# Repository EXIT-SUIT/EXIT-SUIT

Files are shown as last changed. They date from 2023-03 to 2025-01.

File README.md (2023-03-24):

GithubBanner2

# EXIT SUIT
 
The EXIT SUIT is a full-body force-feedback navigation and performance suit for Virtual Reality. This repo contains our code so far for connecting the EXIT SUIT to Unity. 

We are building a community of supporters to help us bring the EXIT SUIT to the public. We recognise it is an important step in the development of human/computer interface and virtual reality.   
<br/><br/> 
ExitImage2   
<br/>
# Community  
 
* Youtube: https://www.youtube.com/@WillieWinkler

* Instagram: https://www.instagram.com/exitsuit/

* Patreon: https://www.patreon.com/EXITSUIT

* Discord: https://discord.gg/Rf7WjFDc

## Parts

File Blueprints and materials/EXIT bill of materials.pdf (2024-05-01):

## Bill of Materials for the EXIT SUIT Revised 31 Jan 2024

CNC cut ply parts- 18mm birch ply
-Use 6mm wide down spiral cutter for cnc machine
I finish my plywood parts with a Wax-oil with added whitener

Spigot
Solid Nylon Bar - 50mm round bar x 260mm long (to be turned on engineering lathe to fit into base bearing 40mm at bottom and up inside tube for 150mm at top)

‘Kingpin’ Metal support column
x1 45mm id Bearing pillow block for base (https://www.ebay.co.uk/itm/UCF-Metric-Self-Lube-Square-Flange-Pillow-Block-Bearing-UCF201-UCF218/222936495315) (bottom bearing) x1 Sealed bearing id 50mm od 90mm width 20mm (https://www.ebay.co.uk/itm/264521502782) (top bearing)
Laser cut 3mm stainless steel components
x1 OD 50mm seamless steel tube 3mm wall (or 5mm wall) (Cold Drawn Seamless in UK or ‘Drawn over Mandrel’ in USA) steel tube (800mm long - shorten to fit crotch height)

It iOS also possible to use a length of easy to find 48.3mm scaffolding tube. The issue here is that it is not so easy to find a sealed bearing (top bearing in base under floorboard) that fits a scaffold tube, so you’d need to turn an additional nylon bush to fit a larger bearing or add vertical welds to the surface of the tube before grinding them back to fit.
Add additional 70mm Nylon round bar x 40mm long (if using this scaffolding tube with bush option and increase top bearing to 60mm id)
Remember the technical drawing for the plywood cutting will need to be adjusted to fit this new bearing size.

Skin
You will need to add a harness or ‘skin’ part to hold yourself into the spine. The simplest way to do this is with a ‘two point safety harness’, customised by having it’s metal hanging point D rings cut off and with holes punched into the belts to enable it to be bolted into the pelvis. https://www.ebay.co.uk/itm/335024775861

Alternatively, you might consider making a leather or canvas version. There are several examples sown in the various EXIT SUIT videos. Fitted custom made skins can be more comfortable and quicker to put on and take off. They might also offer more surface area coverage which is useful if adding haptics and tracking.

Box of 5.0 50mm screws (Torx head)
Box of 5.0 30mm screws (Torx head)
30m 4mm bungee cord (https://www.ebay.co.uk/itm/180822655761)
10m 6mm bungee cord
1m of seatbelts webbing
x30 M6 16mm threaded inserts with flange top (https://www.ebay.co.uk/itm/323306435994) x8 M6 alan drive stainless countersunk bolts (https://www.ebay.co.uk/itm/221298706799?var=520181721468) 60mm X2 M10 stainless 55mm coach bolts (https://www.ebay.co.uk/itm/222339677084?var=521196374967)
X2 M10 stainless 75mm coach bolts
x12 M10 Stainless Nyloc Nuts
x14 M10 washers
x4 M10 60mm countersunk bolts (https://www.ebay.co.uk/itm/360915450505)
X8 30mm OD 10mm ID bearings (https://www.ebay.co.uk/itm/223790691007)
x2 M10 16mm button head bolts (https://www.ebay.co.uk/itm/354197940520)
x4 M8 countersunk 40mm bolts, nuts and washers
x8 38mm rubber feet (https://www.ebay.co.uk/itm/325720224691)
Some 1mm leather (softening ‘disks’ layer for vertebrae feet)

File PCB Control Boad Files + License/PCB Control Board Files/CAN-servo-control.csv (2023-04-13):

Qty | Value | Device | Package | Parts | Description
1 |  | CONN_02 | 1X02 | J4 | Multi connection point. Often used as Generic Header-pin footprint for 0.1 inch spaced/style header connections
1 |  | CONN_06SILK_FEMALE_PTH | 1X06 | J1 | Multi connection point. Often used as Generic Header-pin footprint for 0.1 inch spaced/style header connections
10 |  | SPARKFUN-LED_LED0603 | SPARKFUN-LED_LED-0603 | D1, D2, D3, D4, D5, D6, D7, D8, D9, D10 | LED (Generic)
1 | 0.1uF | SPARKFUN_CAP0603-CAP | SPARKFUN_0603-CAP | C1 | Capacitor
1 | 100uF | CPOL-EUE2.5-5 | E2,5-5 | C3 | POLARIZED CAPACITOR, European symbol
10 | 150 | SPARKFUN-RESISTORS_150OHM-0603-1/10W-1% | SPARKFUN-RESISTORS_0603 | R1, R2, R3, R4, R5, R6, R7, R8, R9, R10 | 150Ω resistor
6 | 455-1750-1-ND | CONN_03 | 1X03 | J3, J5, J6, J7, J8, J9 | Multi connection point. Often used as Generic Header-pin footprint for 0.1 inch spaced/style header connections
1 | 470uF | CPOL-EUE2.5-6 | E2,5-6 | C2 | POLARIZED CAPACITOR, European symbol
1 | RESET | 431256038716 | 431256038716 | S1 | WS-TST, 6*6mm right angle Tact switch,THT, height 3.85mm, 4 pins, black actuator, 160gf
1 | TEENSY_3.6_DIL | TEENSY_3.6_DIL | TEENSY_3.6_DIL | U$1 | Teensy 3.6 DIL Package
1 | XT30PW-M | XT30PW-M | XT30PWM | J2 | 30A Low Temperature Rise Fire Retardant Plug

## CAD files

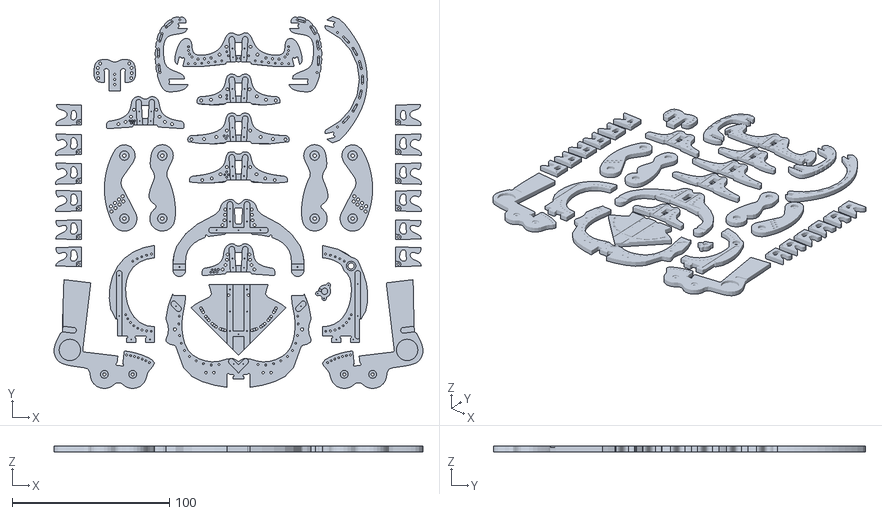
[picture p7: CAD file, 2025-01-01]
Blueprints and materials/1-5-flat EXIT-01.01.2025.stl
234.3 x 236.2 x 3.60

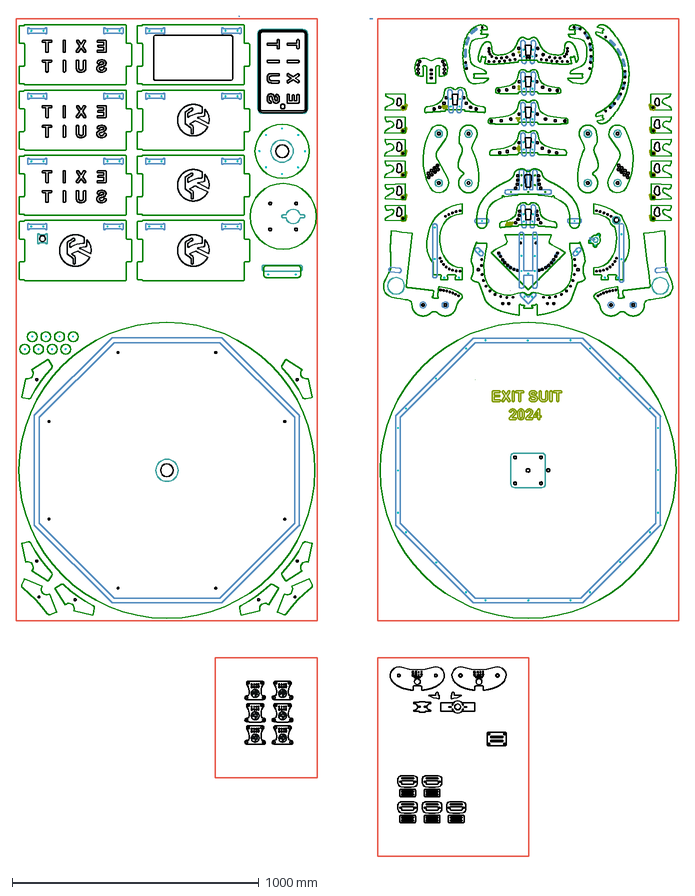
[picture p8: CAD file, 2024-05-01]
Blueprints and materials/EXIT SUIT 2024.dxf
2684.2 x 3405.8 mm

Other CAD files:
Blueprints and materials/assembled-exitsuit.dwg

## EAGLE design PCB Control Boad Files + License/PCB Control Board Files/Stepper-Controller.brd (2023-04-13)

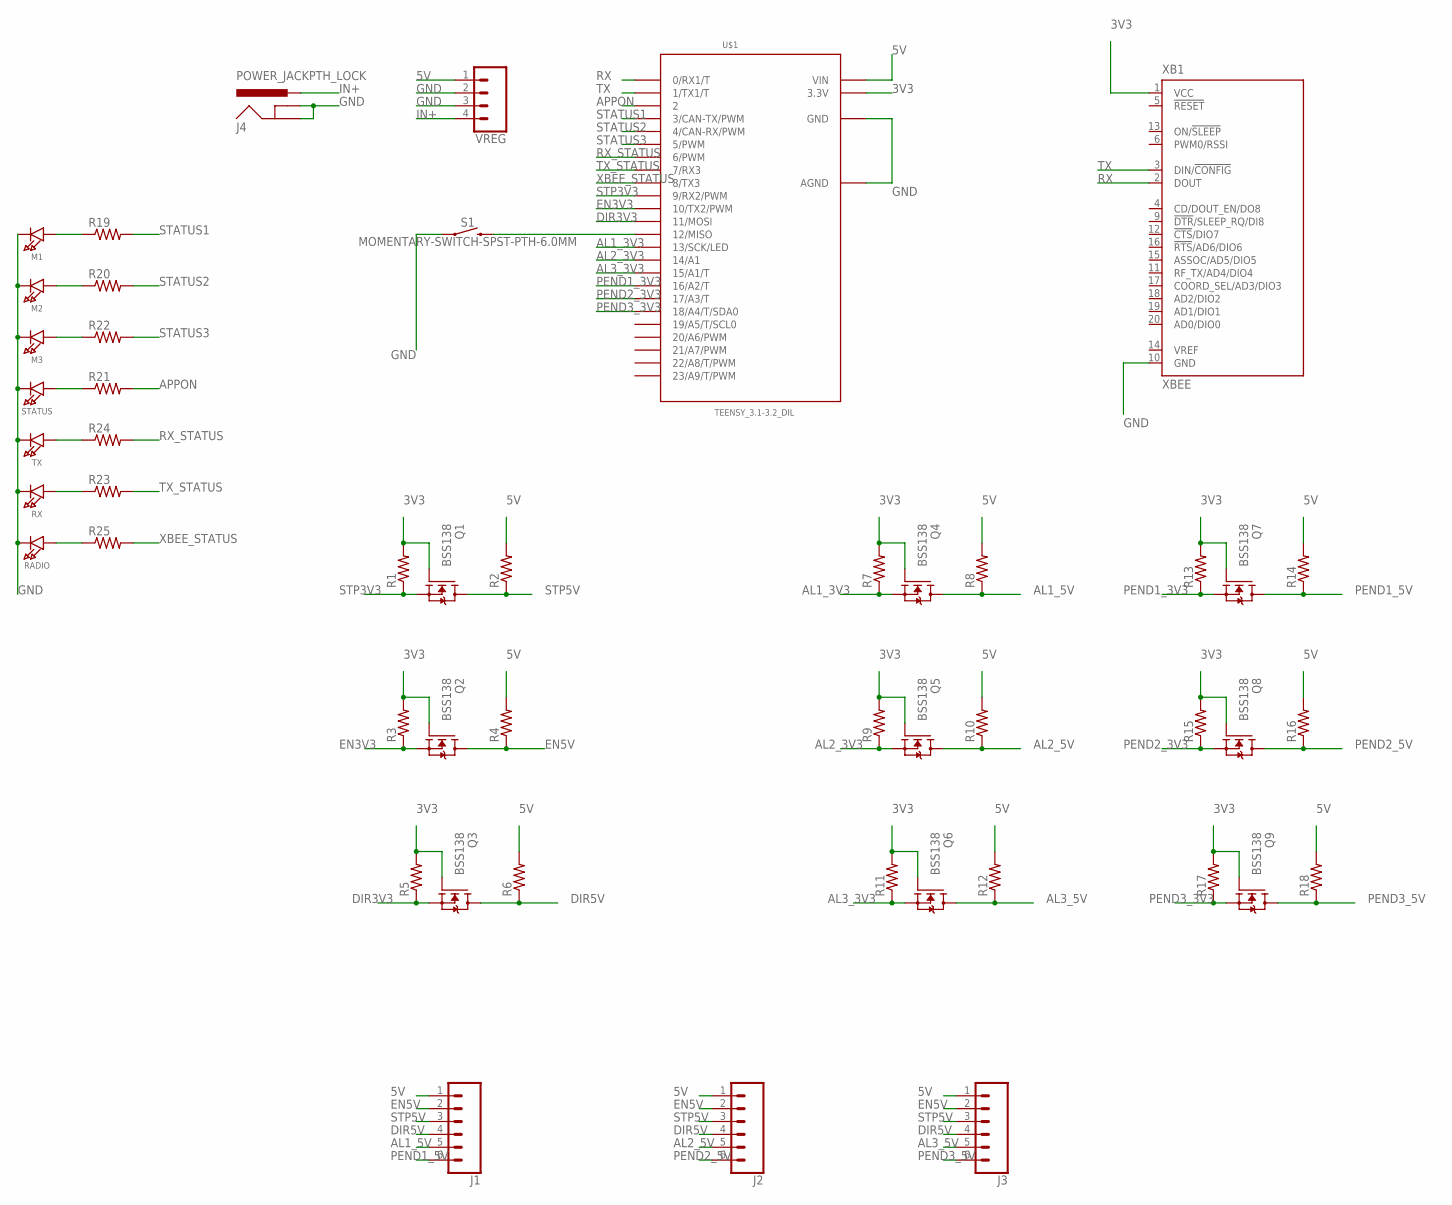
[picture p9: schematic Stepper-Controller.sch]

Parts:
J1, J2, J3: CONN_06NO_SILK_FEMALE_PTH; 1X06_NO_SILK
J4: POWER_JACKPTH_LOCK; POWER_JACK_PTH_LOCK
M1, M2, M3: MICROBUILDER_LED0603; MICROBUILDER_CHIPLED_0603
Q1, Q2, Q3, Q4, Q5, Q6, Q7, Q8, Q9: BSS138; SOT23
R1, R2, R3, R4, R5, R6, R7, R8, R9, R10, R11, R12, R13, R14, R15, R16, R17, R18, R19, R20, R21, R22, R23, R24, R25: CONTROLBOARD_V1.0_SPARKFUN_RESISTOR0603-RES; CONTROLBOARD_V1.0_SPARKFUN_0603-RES
RADIO: MICROBUILDER_LED0603; MICROBUILDER_CHIPLED_0603
RX: MICROBUILDER_LED0603; MICROBUILDER_CHIPLED_0603
S1: MOMENTARY-SWITCH-SPST-PTH-6.0MM; TACTILE_SWITCH_PTH_6.0MM
STATUS: MICROBUILDER_LED0603; MICROBUILDER_CHIPLED_0603
TX: MICROBUILDER_LED0603; MICROBUILDER_CHIPLED_0603
U$1: TEENSY_3.1-3.2_DIL; TEENSY_3.0-3.2&LC_DIL
VREG: CONN_04LONGPADS; 1X04_LONGPADS
XB1: XBEE

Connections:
3V3: Q1.1 (G), Q2.1 (G), Q3.1 (G), Q4.1 (G), Q5.1 (G), Q6.1 (G), Q7.1 (G), Q8.1 (G), Q9.1 (G), R1.2, R3.2, R5.2, R7.2, R9.2, R11.2, R13.2, R15.2, R17.2, U$1.3.3V, XB1.1 (VCC)
5V: J1.1, J2.1, J3.1, R2.2, R4.2, R6.2, R8.2, R10.2, R12.2, R14.2, R16.2, R18.2, U$1.VIN, VREG.1
AL1_3V3: Q4.2 (S), R7.1, U$1.13 (13/SCK/LED)
AL1_5V: J1.5, Q4.3 (D), R8.1
AL2_3V3: Q5.2 (S), R9.1, U$1.14/A0 (14/A1)
AL2_5V: J2.5, Q5.3 (D), R10.1
AL3_3V3: Q6.2 (S), R11.1, U$1.15/A1 (15/A1/T)
AL3_5V: J3.5, Q6.3 (D), R12.1
APPON: R21.2, U$1.2
DIR3V3: Q3.2 (S), R5.1, U$1.11 (11/MOSI)
DIR5V: J1.4, J2.4, J3.4, Q3.3 (D), R6.1
EN3V3: Q2.2 (S), R3.1, U$1.10 (10/TX2/PWM)
EN5V: J1.2, J2.2, J3.2, Q2.3 (D), R4.1
GND: J4.GND, J4.GNDBREAK, M1.C, M2.C, M3.C, RADIO.C, RX.C, S1.1, STATUS.C, TX.C, U$1.AGND, U$1.GND, VREG.2, VREG.3, XB1.10 (GND)
IN+: J4.PWR, VREG.4
unnamed: M1.A, R19.1
unnamed: M2.A, R20.1
unnamed: S1.3 (2), U$1.12 (12/MISO)
unnamed: R21.1, STATUS.A
unnamed: M3.A, R22.1
unnamed: R23.1, RX.A
unnamed: R24.1, TX.A
unnamed: R25.1, RADIO.A
PEND1_3V3: Q7.2 (S), R13.1, U$1.16/A2 (16/A2/T)
PEND1_5V: J1.6, Q7.3 (D), R14.1
PEND2_3V3: Q8.2 (S), R15.1, U$1.17/A3 (17/A3/T)
PEND2_5V: J2.6, Q8.3 (D), R16.1
PEND3_3V3: Q9.2 (S), R17.1, U$1.18/A4 (18/A4/T/SDA0)
PEND3_5V: J3.6, Q9.3 (D), R18.1
RX: U$1.0 (0/RX1/T), XB1.2 (DOUT)
RX_STATUS: R24.2, U$1.6 (6/PWM)
STATUS1: R19.2, U$1.3 (3/CAN-TX/PWM)
STATUS2: R20.2, U$1.4 (4/CAN-RX/PWM)
STATUS3: R22.2, U$1.5 (5/PWM)
STP3V3: Q1.2 (S), R1.1, U$1.9 (9/RX2/PWM)
STP5V: J1.3, J2.3, J3.3, Q1.3 (D), R2.1
TX: U$1.1 (1/TX1/T), XB1.3 (DIN/!CONFIG)
TX_STATUS: R23.2, U$1.7 (7/RX3)
XBEE_STATUS: R25.2, U$1.8 (8/TX3)

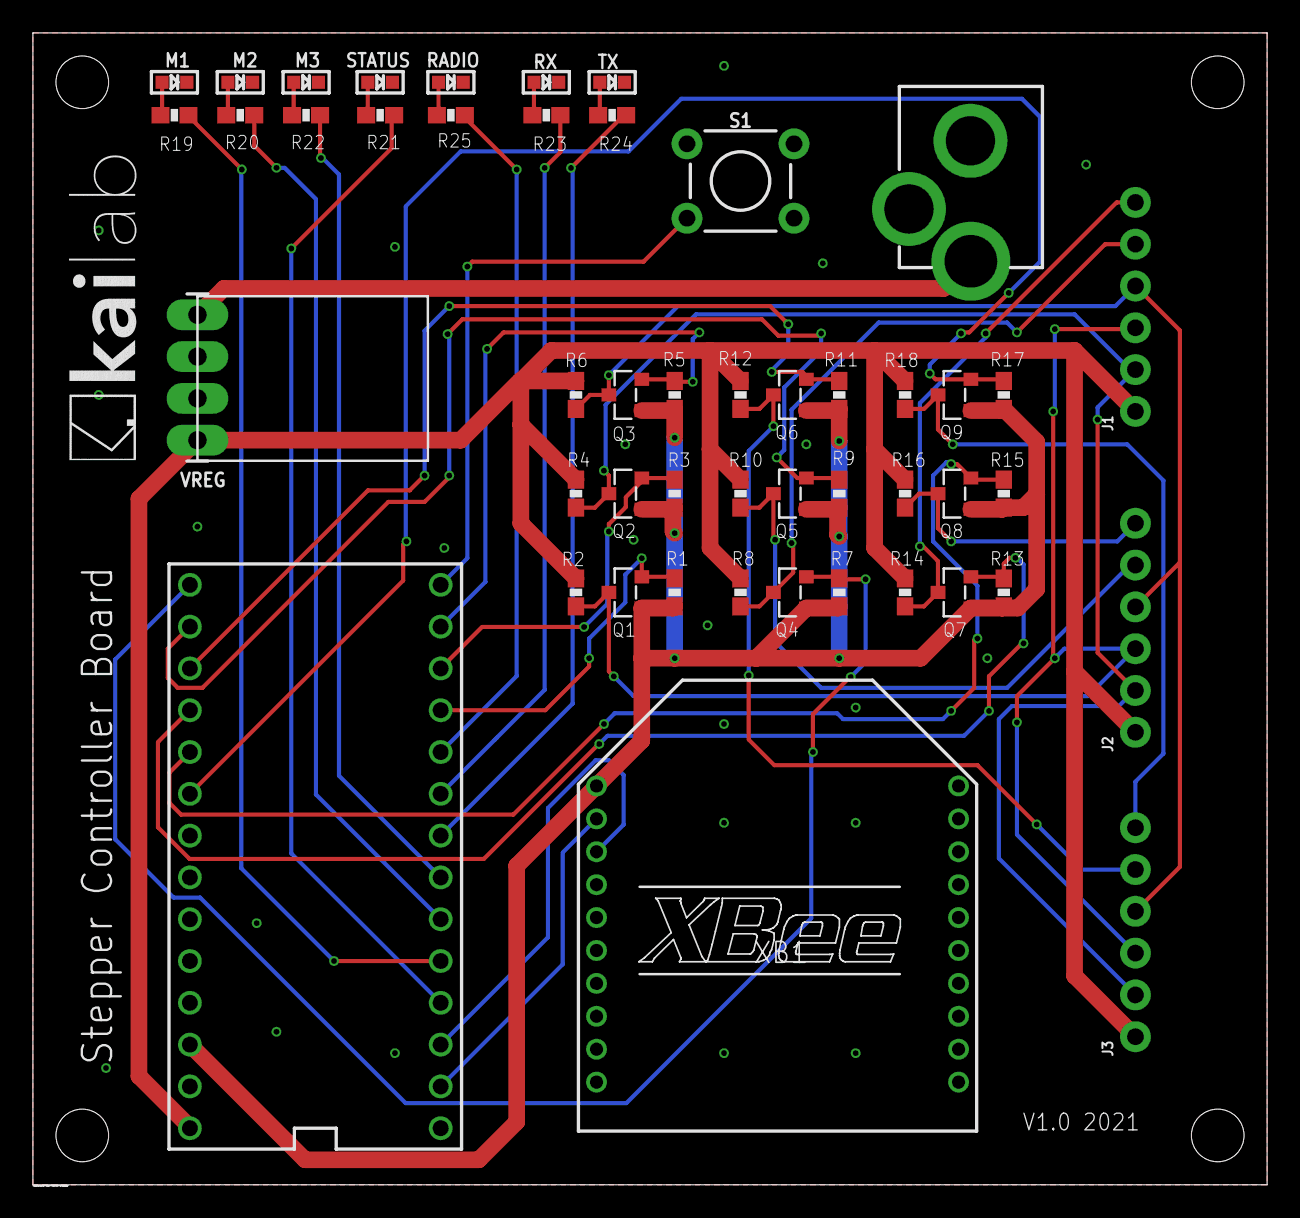
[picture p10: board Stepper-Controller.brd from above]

Board: 2 copper layers, 75.0 x 70.0 mm, 49 parts (0 on the bottom side), 39 nets.

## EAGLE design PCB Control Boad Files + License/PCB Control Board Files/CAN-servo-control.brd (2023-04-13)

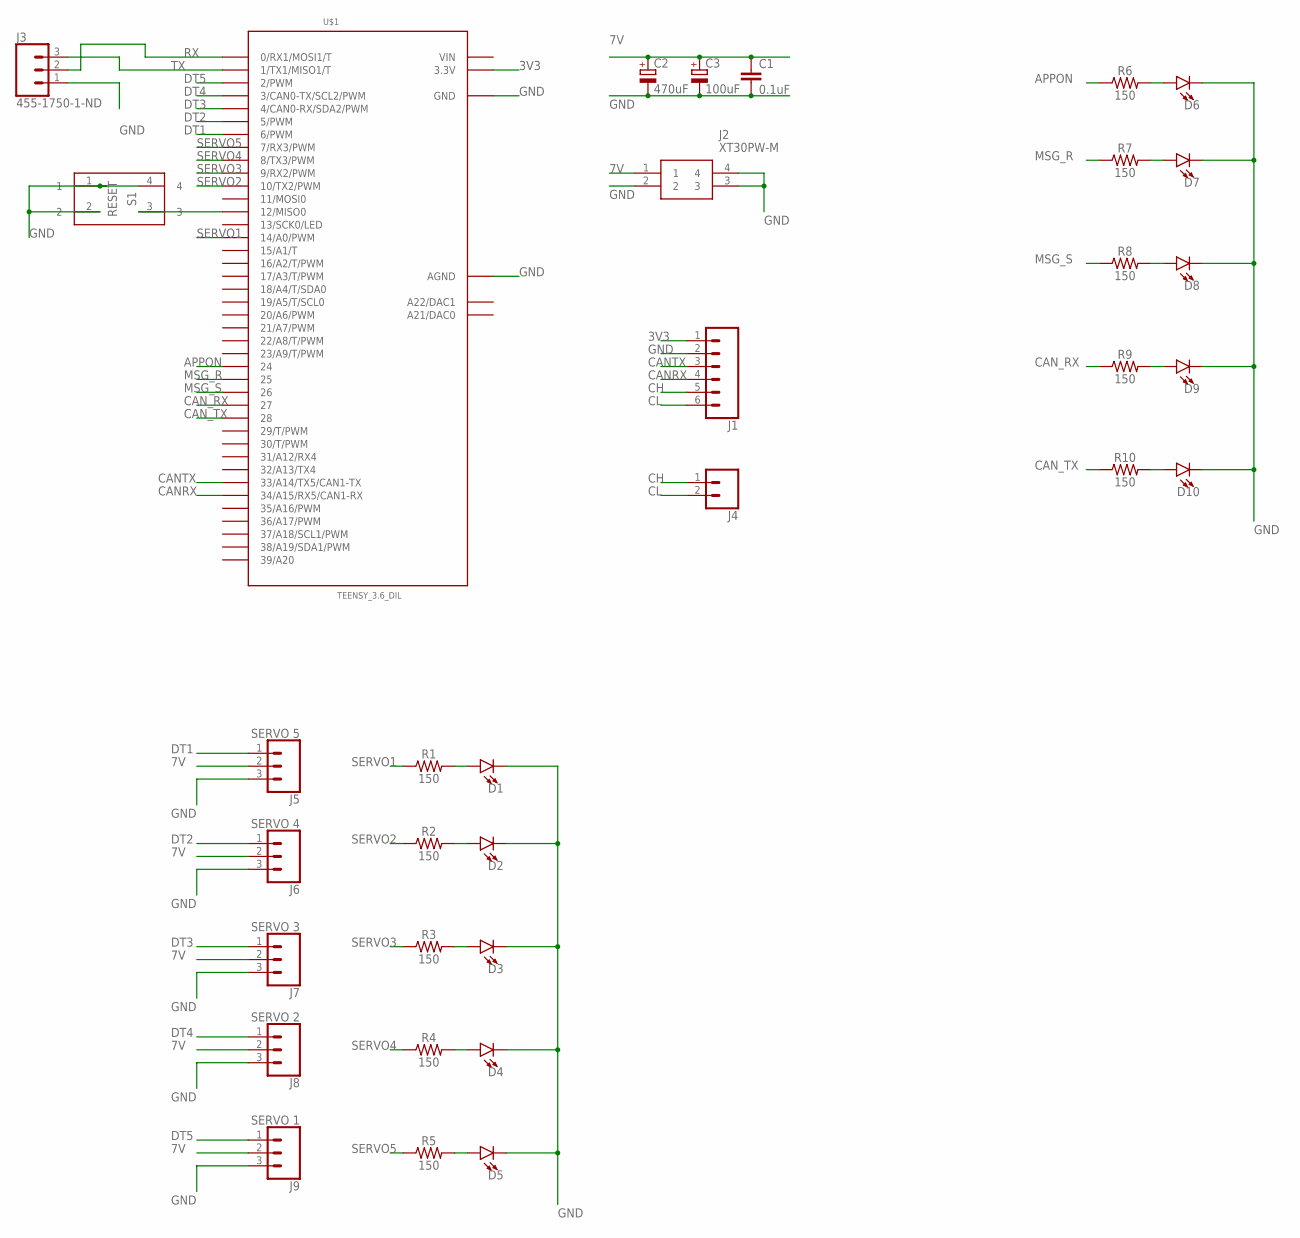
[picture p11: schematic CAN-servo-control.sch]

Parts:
C1: 0.1uF; SPARKFUN_0603-CAP
C2: 470uF; E2,5-6
C3: 100uF; E2,5-5
D1, D2, D3, D4, D5, D6, D7, D8, D9, D10: SPARKFUN-LED_LED0603; SPARKFUN-LED_LED-0603
J1: CONN_06SILK_FEMALE_PTH; 1X06
J2: XT30PW-M; XT30PWM
J3: 455-1750-1-ND; 1X03
J4: CONN_02; 1X02
J5: SERVO 5; 1X03
J6: SERVO 4; 1X03
J7: SERVO 3; 1X03
J8: SERVO 2; 1X03
J9: SERVO 1; 1X03
R1, R2, R3, R4, R5, R6, R7, R8, R9, R10: 150; SPARKFUN-RESISTORS_0603
S1: RESET; 431256038716
U$1: TEENSY_3.6_DIL

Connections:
3V3: J1.1, U$1.3.3V, U$1.3.3V3 (3.3V)
7V: C1.1, C2.+, C3.+, J2.1, J5.2, J6.2, J7.2, J8.2, J9.2
APPON: R6.1, U$1.24
CANRX: J1.4, U$1.34/A15 (34/A15/RX5/CAN1-RX)
CANTX: J1.3, U$1.33/A14 (33/A14/TX5/CAN1-TX)
CAN_RX: R9.1, U$1.27
CAN_TX: R10.1, U$1.28
CH: J1.5, J4.1
CL: J1.6, J4.2
DT1: J5.1, U$1.6 (6/PWM)
DT2: J6.1, U$1.5 (5/PWM)
DT3: J7.1, U$1.4 (4/CAN0-RX/SDA2/PWM)
DT4: J8.1, U$1.3 (3/CAN0-TX/SCL2/PWM)
DT5: J9.1, U$1.2 (2/PWM)
GND: C1.2, C2.-, C3.-, D1.C, D2.C, D3.C, D4.C, D5.C, D6.C, D7.C, D8.C, D9.C, D10.C, J1.2, J2.2, J2.3, J2.4, J3.1, J5.3, J6.3, J7.3, J8.3, J9.3, S1.1, S1.2, S1.4, U$1.AGND, U$1.GND, U$1.GND1 (GND)
MSG_R: R7.1, U$1.25
MSG_S: R8.1, U$1.26
unnamed: S1.3, U$1.12 (12/MISO0)
unnamed: D1.A, R1.2
unnamed: D2.A, R2.2
unnamed: D3.A, R3.2
unnamed: D4.A, R4.2
unnamed: D5.A, R5.2
unnamed: D6.A, R6.2
unnamed: D7.A, R7.2
unnamed: D8.A, R8.2
unnamed: D9.A, R9.2
unnamed: D10.A, R10.2
RX: J3.2, U$1.0 (0/RX1/MOSI1/T)
SERVO1: R1.1, U$1.14/A0 (14/A0/PWM)
SERVO2: R2.1, U$1.10 (10/TX2/PWM)
SERVO3: R3.1, U$1.9 (9/RX2/PWM)
SERVO4: R4.1, U$1.8 (8/TX3/PWM)
SERVO5: R5.1, U$1.7 (7/RX3/PWM)
TX: J3.3, U$1.1 (1/TX1/MISO1/T)
VIN: U$1.VIN

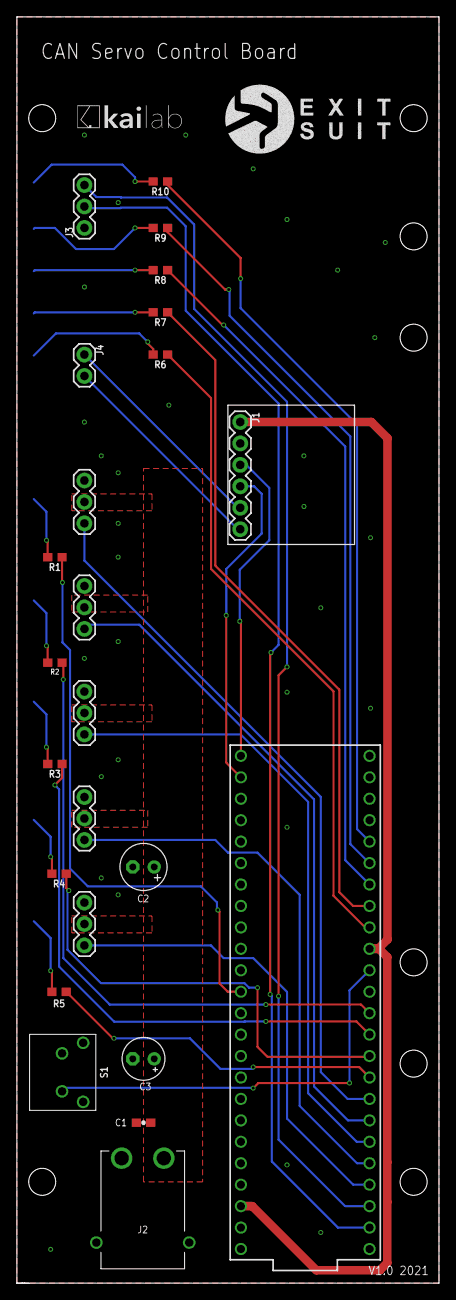
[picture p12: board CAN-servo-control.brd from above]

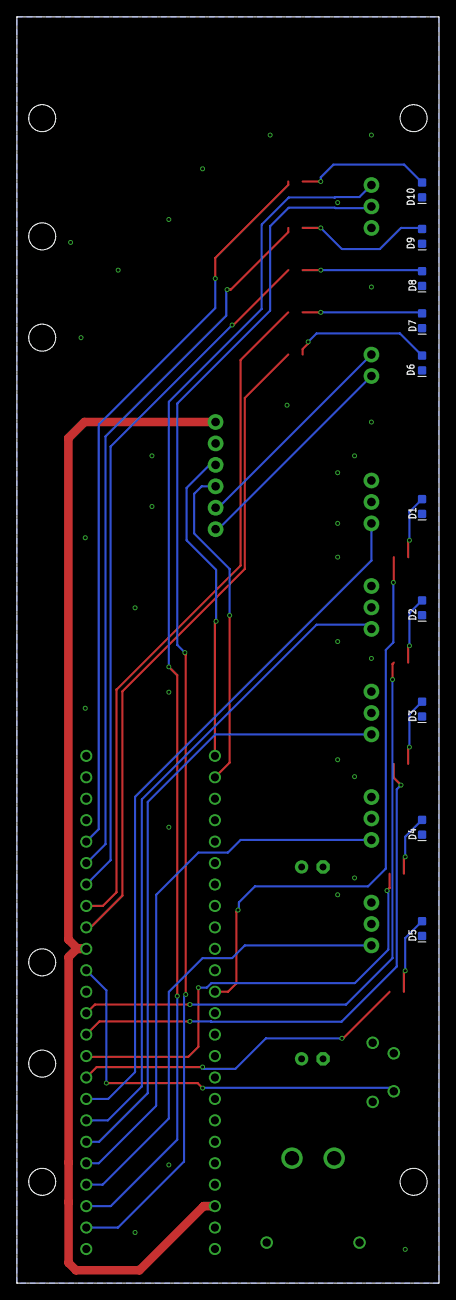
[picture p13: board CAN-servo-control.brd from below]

Board: 2 copper layers, 50.0 x 150.0 mm, 34 parts (10 on the bottom side), 35 nets.

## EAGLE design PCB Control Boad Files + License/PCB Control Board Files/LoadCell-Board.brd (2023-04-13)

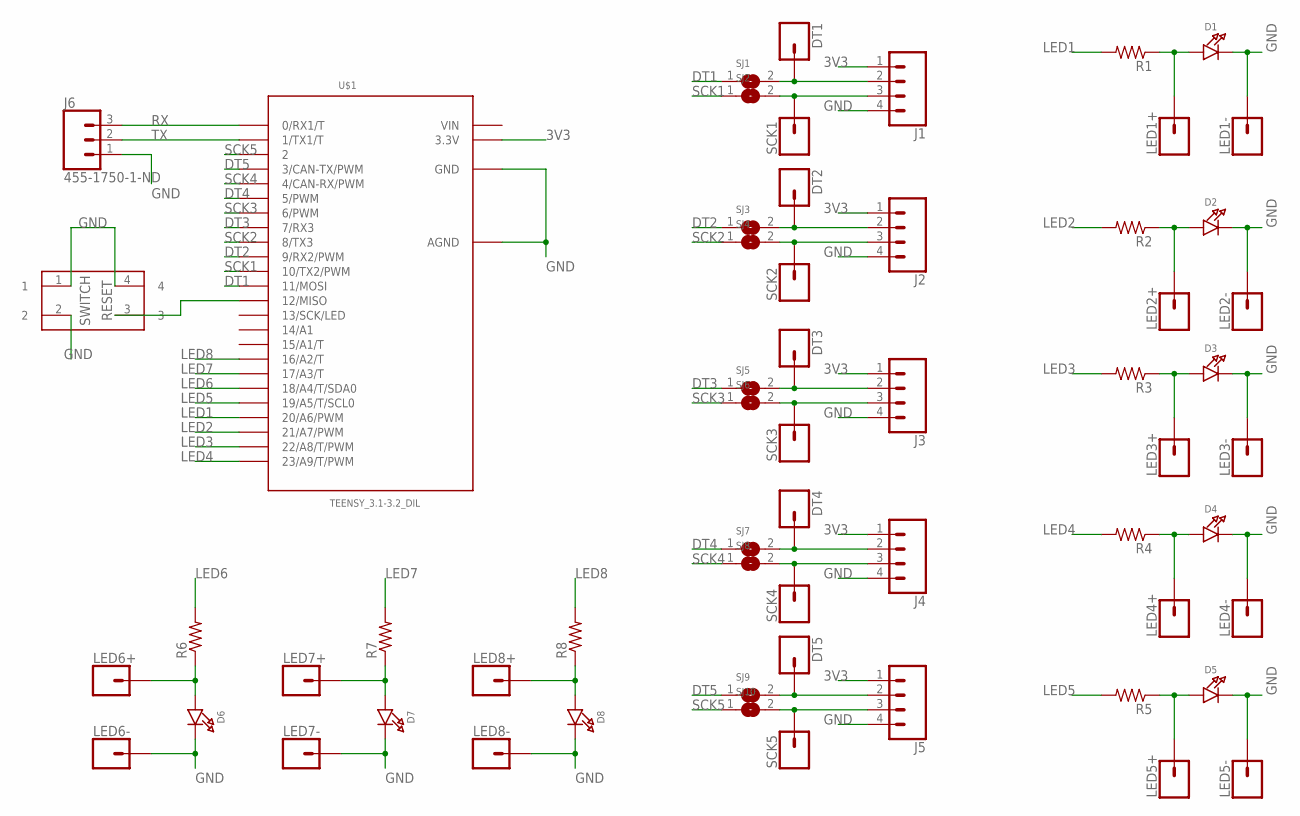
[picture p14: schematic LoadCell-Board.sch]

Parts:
D1, D2, D3, D4, D5, D6, D7, D8: MICROBUILDER_LED0603; MICROBUILDER_CHIPLED_0603
DT1, DT2, DT3, DT4, DT5: CONN_01; 1X01
J1, J2, J3, J4, J5: CONN_041X04_NO_SILK; 1X04_NO_SILK
J6: 455-1750-1-ND; 1X03
LED1+, LED1-, LED2+, LED2-, LED3+, LED3-, LED4+, LED4-, LED5+, LED5-, LED6+, LED6-, LED7+, LED7-, LED8+, LED8-: CONN_01PTH_NO_SILK_YES_STOP; 1X01_NO_SILK
R1, R2, R3, R4, R5, R6, R7, R8: CONTROLBOARD_V1.0_SPARKFUN_RESISTOR0603-RES; CONTROLBOARD_V1.0_SPARKFUN_0603-RES
RESET: SWITCH; 431256038716
SCK1, SCK2, SCK3, SCK4, SCK5: CONN_01; 1X01
SJ1, SJ2, SJ3, SJ4, SJ5, SJ6, SJ7, SJ8, SJ9, SJ10: MICROBUILDER_SOLDERJUMPERREFLOW_NOPASTE; MICROBUILDER_SOLDERJUMPER_REFLOW_NOPASTE
U$1: TEENSY_3.1-3.2_DIL; TEENSY_3.0-3.2&LC_DIL

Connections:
3V3: J1.1, J2.1, J3.1, J4.1, J5.1, U$1.3.3V
DT1: SJ1.1, U$1.11 (11/MOSI)
DT2: SJ3.1, U$1.9 (9/RX2/PWM)
DT3: SJ5.1, U$1.7 (7/RX3)
DT4: SJ7.1, U$1.5 (5/PWM)
DT5: SJ9.1, U$1.3 (3/CAN-TX/PWM)
GND: D1.C, D2.C, D3.C, D4.C, D5.C, D6.C, D7.C, D8.C, J1.4, J2.4, J3.4, J4.4, J5.4, J6.1, LED1-.1, LED2-.1, LED3-.1, LED4-.1, LED5-.1, LED6-.1, LED7-.1, LED8-.1, RESET.1, RESET.2, RESET.4, U$1.AGND, U$1.GND
LED1: R1.2, U$1.20/A6 (20/A6/PWM)
LED2: R2.2, U$1.21/A7 (21/A7/PWM)
LED3: R3.2, U$1.22/A8 (22/A8/T/PWM)
LED4: R4.2, U$1.23/A9 (23/A9/T/PWM)
LED5: R5.2, U$1.19/A5 (19/A5/T/SCL0)
LED6: R6.2, U$1.18/A4 (18/A4/T/SDA0)
LED7: R7.2, U$1.17/A3 (17/A3/T)
LED8: R8.2, U$1.16/A2 (16/A2/T)
unnamed: D1.A, LED1+.1, R1.1
unnamed: DT1.1, J1.2, SJ1.2
unnamed: D2.A, LED2+.1, R2.1
unnamed: J1.3, SCK1.1, SJ2.2
unnamed: D3.A, LED3+.1, R3.1
unnamed: DT2.1, J2.2, SJ3.2
unnamed: RESET.3, U$1.12 (12/MISO)
unnamed: D4.A, LED4+.1, R4.1
unnamed: J2.3, SCK2.1, SJ4.2
unnamed: D5.A, LED5+.1, R5.1
unnamed: DT3.1, J3.2, SJ5.2
unnamed: D6.A, LED6+.1, R6.1
unnamed: J3.3, SCK3.1, SJ6.2
unnamed: D7.A, LED7+.1, R7.1
unnamed: DT4.1, J4.2, SJ7.2
unnamed: D8.A, LED8+.1, R8.1
unnamed: J4.3, SCK4.1, SJ8.2
unnamed: DT5.1, J5.2, SJ9.2
unnamed: J5.3, SCK5.1, SJ10.2
RX: J6.3, U$1.0 (0/RX1/T)
SCK1: SJ2.1, U$1.10 (10/TX2/PWM)
SCK2: SJ4.1, U$1.8 (8/TX3)
SCK3: SJ6.1, U$1.6 (6/PWM)
SCK4: SJ8.1, U$1.4 (4/CAN-RX/PWM)
SCK5: SJ10.1, U$1.2
TX: J6.2, U$1.1 (1/TX1/T)
VIN: U$1.VIN

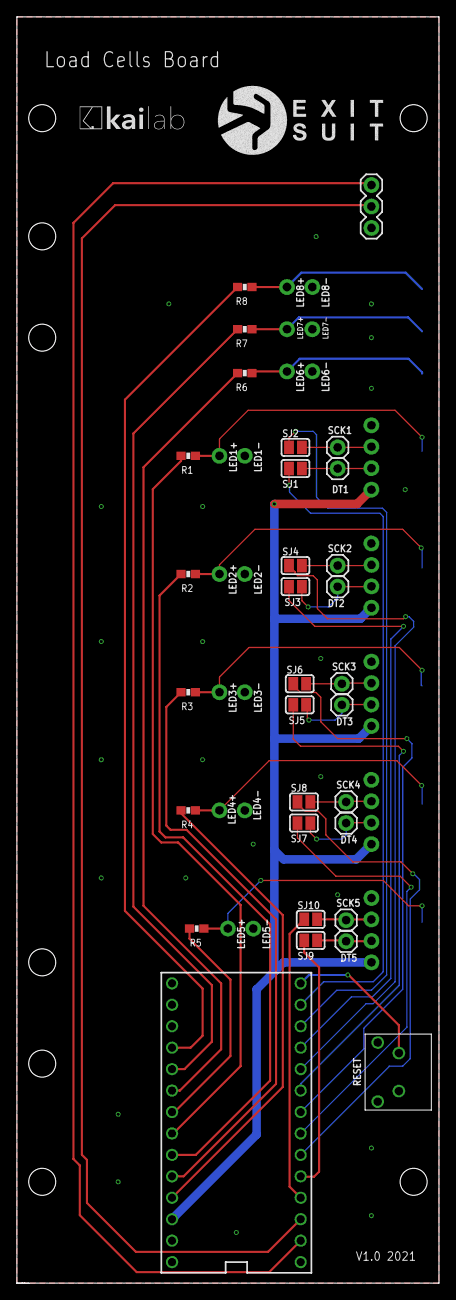
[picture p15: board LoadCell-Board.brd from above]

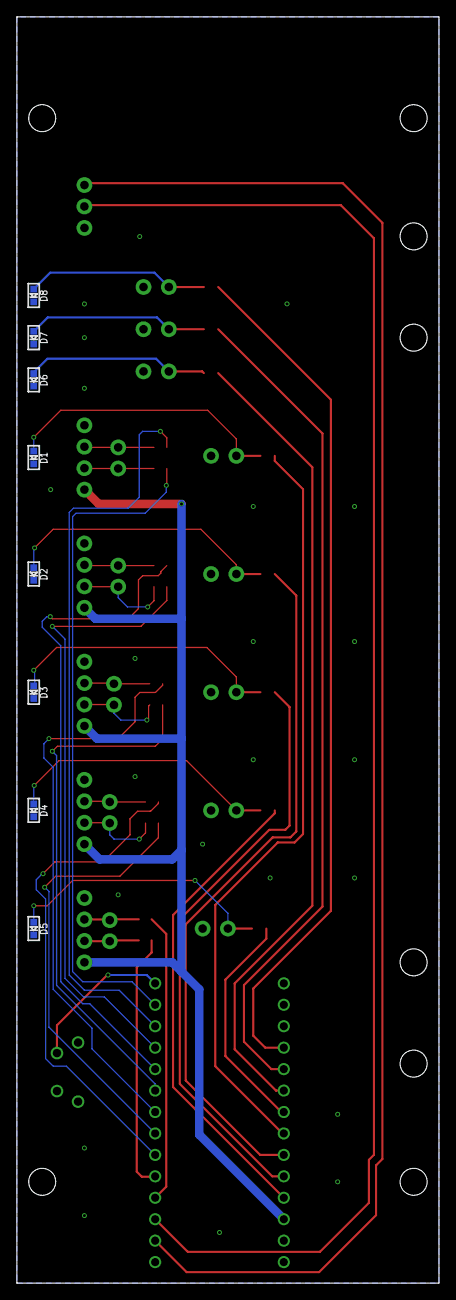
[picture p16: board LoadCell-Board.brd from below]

Board: 2 copper layers, 50.0 x 150.0 mm, 60 parts (8 on the bottom side), 41 nets.

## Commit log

2023-04-13 Add files via upload
    Files for the EXIT SUIT's first prototype PCB control board
    Can-Servo control with Gerber files
    [CAN-servo-control.brd, CAN-servo-control.csv, CAN-servo-control.sch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]
2023-04-13 Add files via upload
    Files for the EXIT SUIT first PCB control board
    Load-cell board and Gerber files
    [LoadCell-Board.brd, LoadCell-Board.sch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]
2023-04-13 Add files via upload
    Files for the EXIT SUIT's first PCB control board
    Stepper control and Gerber Files
    [Stepper-Controller.brd, Stepper-Controller.sch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]
2023-04-13 PCB Control Board files
    PCB Control Board files
    [CAN-servo-control.brd, CAN-servo-control.csv, CAN-servo-control.sch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]
2024-05-01 Create EXIT SUIT PCB control board files
2024-05-01 Rename license.txt to Blueprints and materials/license.txt
2024-05-01 Moving PCB Folder
2024-05-01 Moving PCB Files
2024-08-28 Delete Blueprints and materials/assembled.dwg
    Updating file with correct layer names
    [assembled.dwg]

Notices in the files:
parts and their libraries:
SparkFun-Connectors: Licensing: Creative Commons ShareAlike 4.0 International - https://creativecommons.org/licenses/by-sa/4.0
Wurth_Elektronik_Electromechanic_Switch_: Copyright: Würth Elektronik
